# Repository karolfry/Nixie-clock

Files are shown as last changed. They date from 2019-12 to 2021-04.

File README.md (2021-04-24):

# Nixie-clock-ESP32
My new nixie clock  project based on esp32 lolin lite and LC-516 nixie tubes

Main componnents:
-ESP32 lolin lite 
-Nixie lamps LC-516
-Nixie drivers 74141
-Scift registers 74HC595
-HV voltage converter 

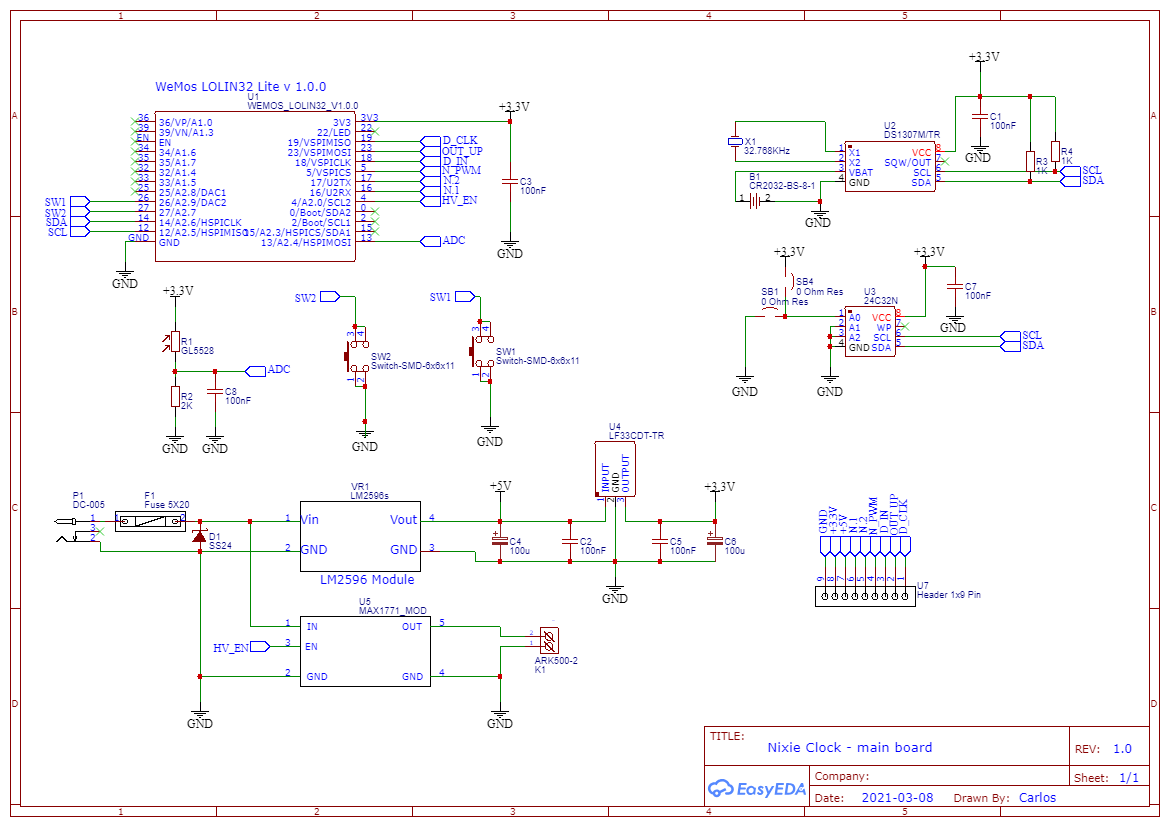
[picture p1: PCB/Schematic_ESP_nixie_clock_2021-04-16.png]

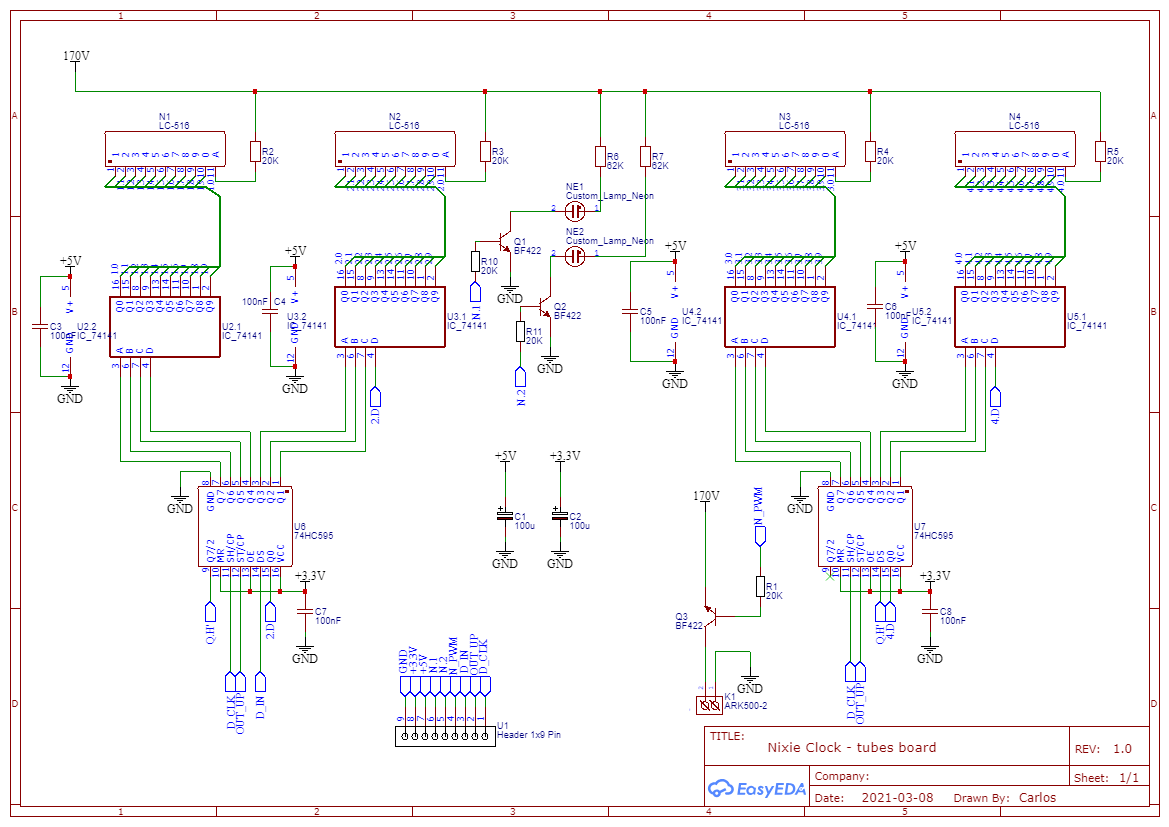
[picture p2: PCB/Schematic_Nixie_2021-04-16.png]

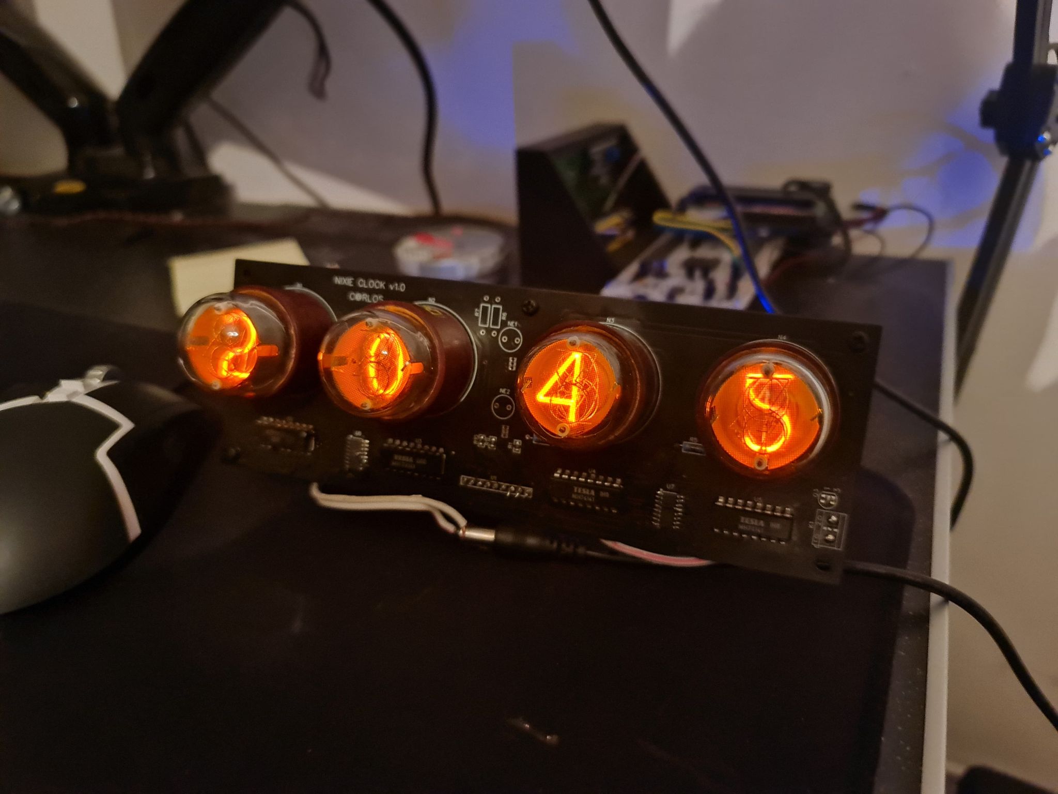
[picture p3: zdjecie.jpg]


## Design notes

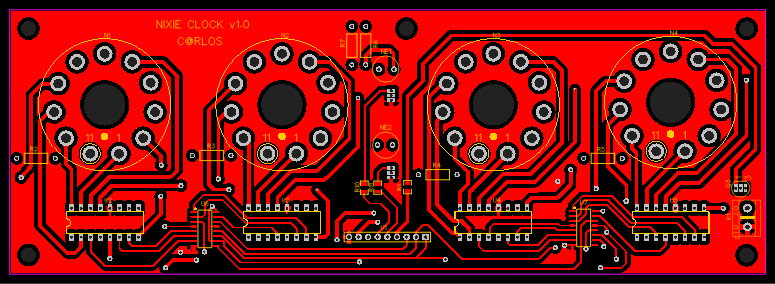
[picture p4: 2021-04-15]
PCB/PCB_Nixie_PCB_2021-04-16.png

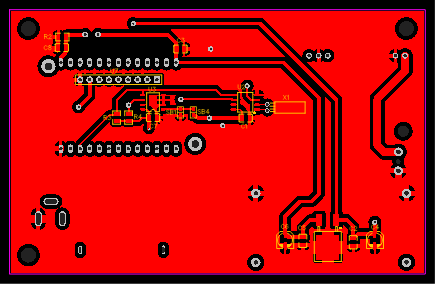
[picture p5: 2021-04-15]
PCB/PCB_Main_PCB_2021-04-16.png

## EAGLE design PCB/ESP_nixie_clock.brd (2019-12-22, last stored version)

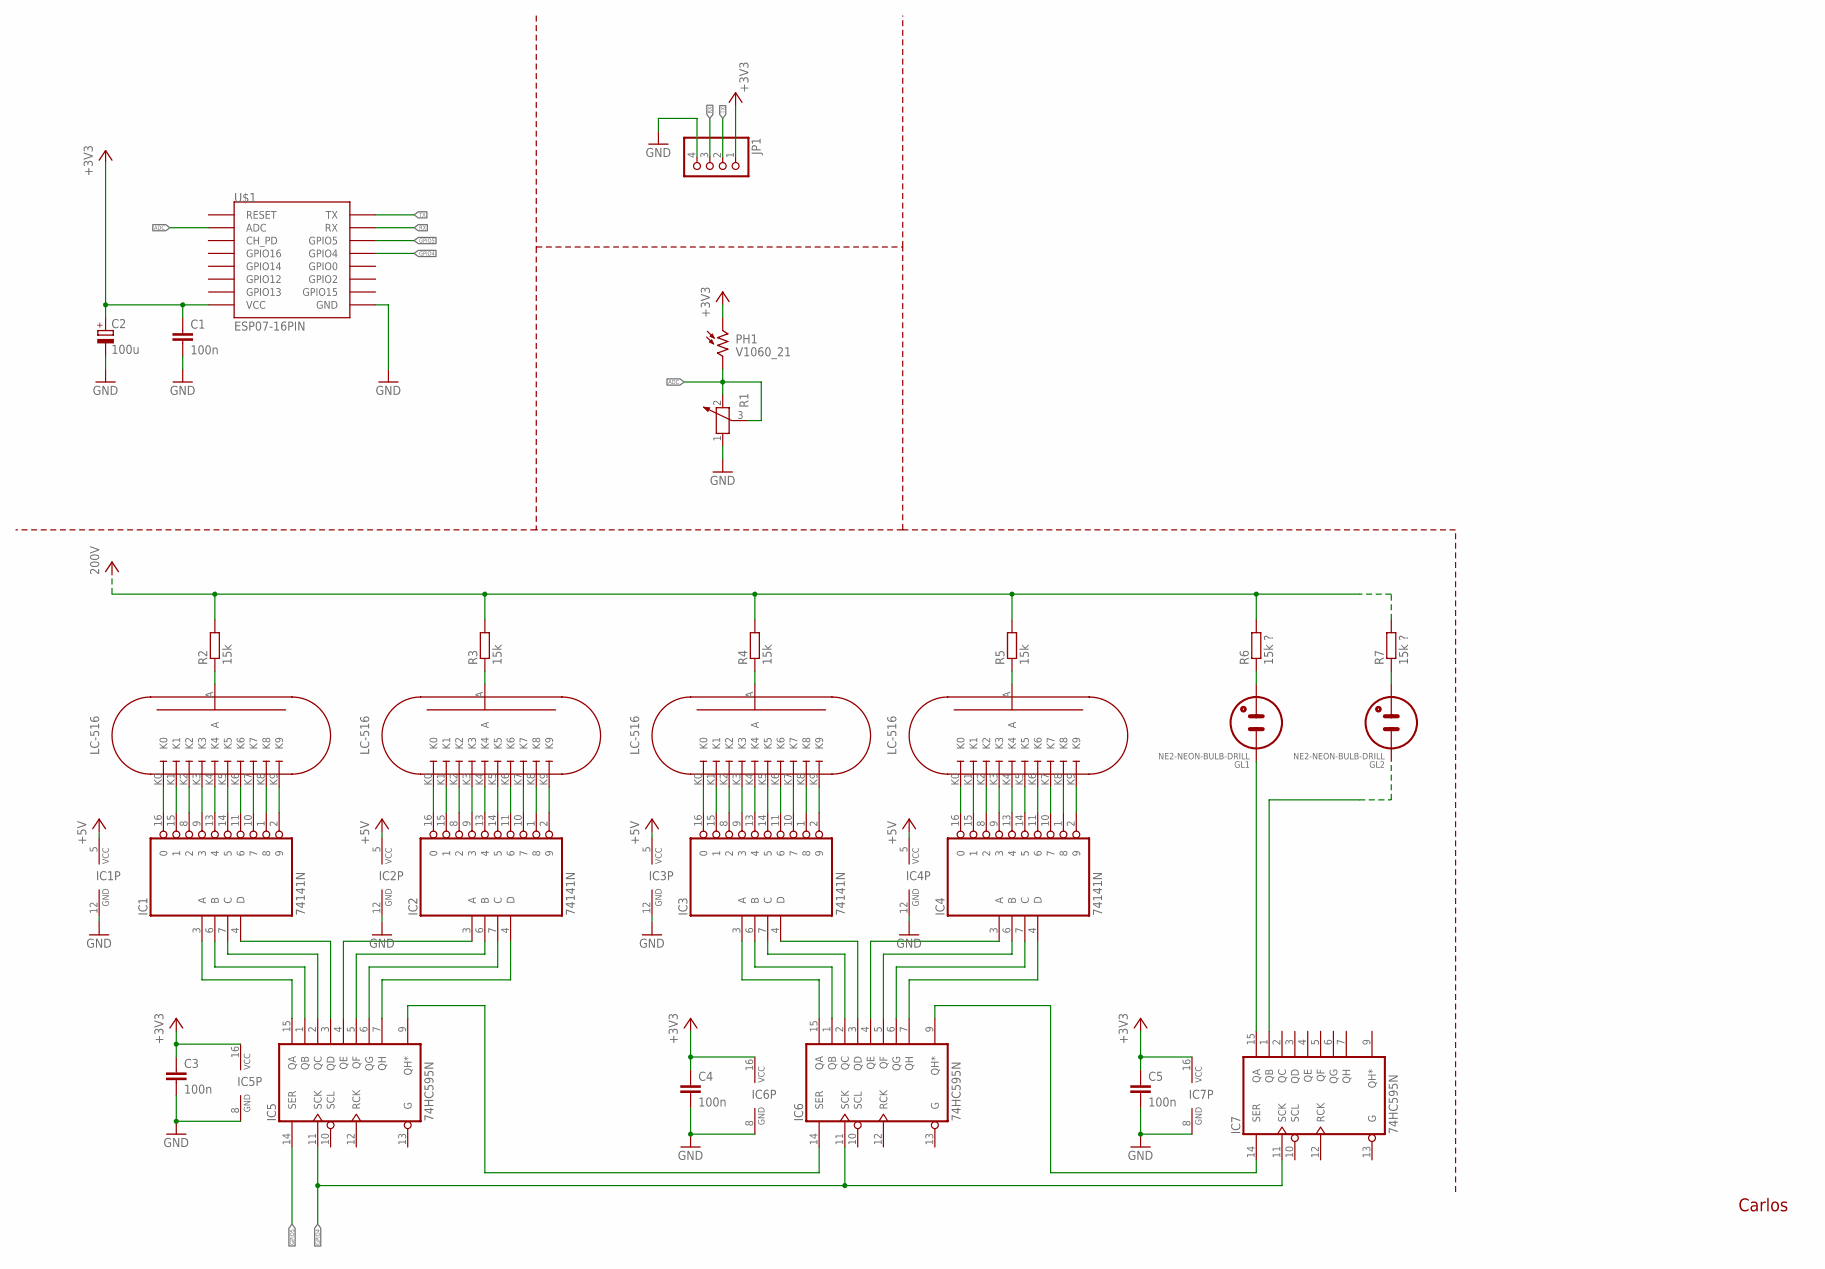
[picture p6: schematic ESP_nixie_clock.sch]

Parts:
C1, C3, C4, C5: 100n; C0805K
C2: 100u; 153CLV-0810
GL1, GL2: NE2-NEON-BULB-DRILL
IC1, IC2, IC3, IC4: 74141N; DIL16
IC5, IC6, IC7: 74HC595N; DIL16
JP1: PINHD-1X4/90; 1X04/90
PH1: V1060_21; TO-5_V10
R1: POTENTIOMETER_PT-10; PT-10
R2, R3, R4, R5: 15k; 0207/10
R6, R7: 15k ?; 0207/10
U$1: ESP07-16PIN
U$2, U$3, U$4, U$5: LC-516

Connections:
+3V3: C1.1, C2.+, C3.1, C4.1, C5.1, IC5.16 (VCC), IC6.16 (VCC), IC7.16 (VCC), JP1.1, PH1.1, U$1.VCC
+5V: IC1.5 (VCC), IC2.5 (VCC), IC3.5 (VCC), IC4.5 (VCC)
ADC: PH1.2, R1.2, R1.3, U$1.ADC
GND: C1.2, C2.-, C3.2, C4.2, C5.2, IC1.12 (GND), IC2.12 (GND), IC3.12 (GND), IC4.12 (GND), IC5.8 (GND), IC6.8 (GND), IC7.8 (GND), JP1.4, R1.1, U$1.GND
GPIO4: IC5.11 (SCK), IC6.11 (SCK), IC7.11 (SCK), U$1.GPIO5 (GPIO4)
GPIO5: IC5.14 (SER), U$1.GPIO4 (GPIO5)
unnamed: IC1.16 (0), U$2.K0
unnamed: IC1.15 (1), U$2.K1
unnamed: IC1.8 (2), U$2.K2
unnamed: IC1.9 (3), U$2.K3
unnamed: IC1.13 (4), U$2.K4
unnamed: IC1.11 (6), U$2.K6
unnamed: IC1.14 (5), U$2.K5
unnamed: IC1.10 (7), U$2.K7
unnamed: IC1.1 (8), U$2.K8
unnamed: IC1.2 (9), U$2.K9
unnamed: IC2.16 (0), U$3.K0
unnamed: IC2.15 (1), U$3.K1
unnamed: IC2.8 (2), U$3.K2
unnamed: IC2.9 (3), U$3.K3
unnamed: IC2.13 (4), U$3.K4
unnamed: IC2.14 (5), U$3.K5
unnamed: IC2.11 (6), U$3.K6
unnamed: IC2.10 (7), U$3.K7
unnamed: IC2.1 (8), U$3.K8
unnamed: IC2.2 (9), U$3.K9
unnamed: IC3.16 (0), U$4.K0
unnamed: IC3.15 (1), U$4.K1
unnamed: IC3.8 (2), U$4.K2
unnamed: IC3.9 (3), U$4.K3
unnamed: IC3.13 (4), U$4.K4
unnamed: IC3.14 (5), U$4.K5
unnamed: IC3.11 (6), U$4.K6
unnamed: IC3.10 (7), U$4.K7
unnamed: IC3.1 (8), U$4.K8
unnamed: IC3.2 (9), U$4.K9
unnamed: IC4.16 (0), U$5.K0
unnamed: IC4.15 (1), U$5.K1
unnamed: IC4.8 (2), U$5.K2
unnamed: IC4.9 (3), U$5.K3
unnamed: IC4.13 (4), U$5.K4
unnamed: IC4.14 (5), U$5.K5
unnamed: IC4.11 (6), U$5.K6
unnamed: IC4.10 (7), U$5.K7
unnamed: IC4.1 (8), U$5.K8
unnamed: IC4.2 (9), U$5.K9
unnamed: IC1.3 (A), IC5.15 (QA)
unnamed: IC1.6 (B), IC5.1 (QB)
unnamed: IC1.7 (C), IC5.2 (QC)
unnamed: IC1.4 (D), IC5.3 (QD)
unnamed: IC2.3 (A), IC5.4 (QE)
unnamed: IC2.6 (B), IC5.5 (QF)
unnamed: IC2.7 (C), IC5.6 (QG)
unnamed: IC2.4 (D), IC5.7 (QH)
unnamed: IC5.9 (QH*), IC6.14 (SER)
unnamed: IC3.3 (A), IC6.15 (QA)
unnamed: IC3.6 (B), IC6.1 (QB)
unnamed: IC3.7 (C), IC6.2 (QC)
unnamed: IC3.4 (D), IC6.3 (QD)
unnamed: IC4.3 (A), IC6.4 (QE)
unnamed: IC4.6 (B), IC6.5 (QF)
unnamed: IC4.7 (C), IC6.6 (QG)
unnamed: IC4.4 (D), IC6.7 (QH)
unnamed: IC6.9 (QH*), IC7.14 (SER)
unnamed: R2.1, U$2.A
unnamed: GL1.1 (A), IC7.15 (QA)
unnamed: GL2.1 (A), IC7.1 (QB)
unnamed: R3.1, U$3.A
unnamed: R4.1, U$4.A
unnamed: R5.1, U$5.A
unnamed: GL1.2 (A1), R6.1
unnamed: GL2.2 (A1), R7.1
RX: JP1.3, U$1.RX
TX: JP1.2, U$1.TX
VCC: R2.2, R3.2, R4.2, R5.2, R6.2, R7.2

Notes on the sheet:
Carlos

Board: 2 copper layers, 28 parts (0 on the bottom side), 75 nets, no tracks yet.

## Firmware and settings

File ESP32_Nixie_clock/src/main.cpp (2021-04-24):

#include <Arduino.h>
#include <WiFi.h>
#include <time.h>

#define HV_PIN 4
#define LED_PIN 22
#define OUT_UP_PIN 23
#define D_CLK_PIN 19
#define D_IN_PIN 18

#define SW_1_PIN 26
#define SW_2_PIN 27



//  Zmienna do zapisu sekwencji dla rejestrów przesównych
//
//          U1 U2 : U3 U4
//
//       U2     U1    U4    U3
//      0000   0000  0000  0000
uint16_t SR_tab = 0;

const char* ssid     = "multimedia_karol";
const char* password = "V9CgmmkeuyMi6E3";

const char* ntpServer = "pool.ntp.org";
const long  gmtOffset_sec = 0;
const int   daylightOffset_sec = 7200;
//const int   daylightOffset_sec = 0;

void Display_update(){

  for(uint8_t x=0 ;x<=15; x++)
  {
    if(SR_tab & (1<<x)) digitalWrite(D_IN_PIN,HIGH);
    else digitalWrite(D_IN_PIN,LOW);

    digitalWrite(D_CLK_PIN,LOW);
    delay(1);
    digitalWrite(D_CLK_PIN,HIGH);

  }
  digitalWrite(OUT_UP_PIN,LOW);
  delay(1);
  digitalWrite(OUT_UP_PIN,HIGH);
}

void Display_set_time(uint8_t hours, uint8_t minutes)
{
  SR_tab = 0;

  uint16_t d_hours, u_hours, d_minutes, u_minutes;
  d_hours = hours/10;
  u_hours = hours%10;
  d_minutes = minutes/10;
  u_minutes = minutes%10; 
  
  SR_tab |= (d_hours << 8) | (u_hours << 12) | d_minutes | (u_minutes<<4);

  Display_update();
}

void printLocalTime(){
  struct tm timeinfo;
  if(!getLocalTime(&timeinfo)){
    Serial.println("Failed to obtain time");
    return;
  }
  Serial.println(&timeinfo, "%A, %B %d %Y %H:%M:%S");
  Serial.print("Day of week: ");
  Serial.println(&timeinfo, "%A");
  Serial.print("Month: ");
  Serial.println(&timeinfo, "%B");
  Serial.print("Day of Month: ");
  Serial.println(&timeinfo, "%d");
  Serial.print("Year: ");
  Serial.println(&timeinfo, "%Y");
  Serial.print("Hour: ");
  Serial.println(&timeinfo, "%H");
  Serial.print("Hour (12 hour format): ");
  Serial.println(&timeinfo, "%I");
  Serial.print("Minute: ");
  Serial.println(&timeinfo, "%M");
  Serial.print("Second: ");
  Serial.println(&timeinfo, "%S");

  Serial.println("Time variables");
  char timeHour[3];
  strftime(timeHour,3, "%H", &timeinfo);
  Serial.println(timeHour);
  char timeWeekDay[10];
  strftime(timeWeekDay,10, "%A", &timeinfo);
  Serial.println(timeWeekDay);
  Serial.println();

  Display_set_time(timeinfo.tm_hour,timeinfo.tm_min);

}

void setup() {
   //Schift Reg gpio config 
   pinMode(LED_PIN,OUTPUT);
   pinMode(D_IN_PIN,OUTPUT);
   pinMode(OUT_UP_PIN,OUTPUT);
   pinMode(D_CLK_PIN,OUTPUT);

  // HV ON
  delay(3000);
  pinMode(HV_PIN,OUTPUT);
  digitalWrite(HV_PIN,LOW);

  //UART Config
  Serial.begin(115200);
  Serial.print("Hello esp");

  //WiFi connect
  WiFi.begin(ssid, password);
  while (WiFi.status() != WL_CONNECTED) {
  delay(500);
  Serial.print(".");
  }
  Serial.println("");
  Serial.println("WiFi connected.");

  //Display test
  for(uint8_t i=0; i<2;i++)
  {
    for(uint8_t x =0;x<10;x++)
    {
    Display_set_time (x*11,x*11);
    delay(300);
    }
  }

  // Init and get the time
  configTime(gmtOffset_sec, daylightOffset_sec, ntpServer);
  printLocalTime();


}

void loop() {
 // put your main code here, to run repeatedly:
  // digitalWrite(LED_PIN,HIGH);

  //delay(80);
  //digitalWrite(LED_PIN,LOW);

  //delay(80);
  //digitalWrite(LED_PIN,HIGH);

  printLocalTime();
  delay(900);

  

// for(uint8_t x =10;x<20;x++)
  // {
    // for(uint8_t y=0;y<100;y++)
    // {
      //  Display_set_time (x,y);
      //  delay(100);
    // }
  // }

// for(uint8_t x =0;x<10;x++)
// {
// Display_set_time (x*11,x*11);
// delay(300);
// }
// 
 // Display_set_time (77,77);
}

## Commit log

2019-12-22 Add draft version of schematic, modified README, add datasheet
    [ESP_nixie_clock.brd, ESP_nixie_clock.sch]
2021-04-15 pcb update
    [ESP_nixie_clock.brd, ESP_nixie_clock.sch]
